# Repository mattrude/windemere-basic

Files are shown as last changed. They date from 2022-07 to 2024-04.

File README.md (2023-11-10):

# Windemere Basic 6502 Computer

This is a proof of concept project to build a 65c02 computer from scratch.

This repository is broken up into 2 main sections, [Hardware](Hardware#readme) and [Software](SourceCode#readme).

## About

                 ┌───────────────────────────┐
                 │    WD65C02 Memory Map     │
                 ├───────┬───────────────────┤
                 │ $0000 │                   │
                 │       │   Zero Page RAM   │
                 │ $00ff │                   │
                 ├───────┼───────────────────┤
                 │ $0100 │///////////////////│
                 │       │////// Stack //////│
                 │ $01ff │///////////////////│
                 ├───────┼───────────────────┤
                 │ $0200 │                   │
                 │       │        RAM        │
                 │ $5fff │                   │
                 ├───────┼───────────────────┤
                 │ $6000 │                   │
                 │       │    W65C22S VIA    │
                 │ $600f │                   │
                 ├───────┼───────────────────┤
                 │ $6010 │                   │
                 │       │    (Not Used)     │
                 │ $7fff │                   │
                 ├───────┼───────────────────┤
                 │ $8000 │                   │
                 │       │        ROM        │
                 │ $ffff │                   │
                 └───────┴───────────────────┘

     ┌────────────────────────────────────────────────────────┐
     │                 Zero Page RAM Locations                │
     ├────────────────────────────────────────────────────────┤
     │ 0000: -- -- -- -- -- -- -- --  -- -- -- -- -- -- -- -- │
     │ 0010: -- -- -- -- -- -- -- --  -- -- -- -- -- -- -- -- │
     │ 0020: -- -- -- -- -- -- -- --  -- -- -- -- -- -- -- -- │
     │ 0030: -- -- -- -- -- -- -- --  -- -- -- -- -- -- -- -- │
     │ 0040: -- -- -- -- -- -- -- --  -- -- -- -- -- -- -- -- │
     │ 0050: -- -- -- -- -- -- -- --  -- -- -- -- -- -- -- -- │
     │ 0060: -- -- -- -- -- -- -- --  -- -- -- -- -- -- -- -- │
     │ 0070: -- -- -- -- -- -- -- --  -- -- -- -- -- -- -- -- │
     │ 0080: -- -- -- -- -- -- -- --  -- -- -- -- -- -- -- -- │
     │ 0090: -- -- -- -- -- -- -- --  -- -- -- -- -- -- -- -- │
     │ 00a0: -- -- -- -- -- -- -- --  -- -- -- -- -- -- -- -- │
     │ 00b0: -- -- -- -- -- -- -- --  -- -- -- -- -- -- -- -- │
     │ 00c0: -- -- -- -- -- -- -- --  -- -- -- -- -- -- -- -- │
     │ 00d0: -- -- -- -- -- -- -- --  -- -- -- -- -- -- -- -- │
     │ 00e0: -- -- -- -- -- -- -- --  -- -- -- -- -- -- -- -- │
     │ 00f0: 00 00 00 00 00 00 00 00  -- -- -- -- -- -- -- -- │
     └────────────────────────────────────────────────────────┘

## Required Tools/Software

### Software Used

* [KiCad](https://www.kicad.org/) - To create the Schematic and PCB
* [vasm](http://sun.hasenbraten.de/vasm/) - To compile the Source Code
* [miniPro](https://gitlab.com/DavidGriffith/minipro) - To upload the compiled binary to an eeprom
* [ClickCharts](https://www.nchsoftware.com/chart/index.html) - To create flowchart's for project documentation.

### Compiling from source

This source file expects the use of the vasm compiler found at: [sun.hasenbraten.de/vasm](http://sun.hasenbraten.de/vasm/)

To compile this code, run a command similer to:

    vasm6502_oldstyle -c02 -dotdir -Fbin main.asm -o main.bin

## System Images

Schematic

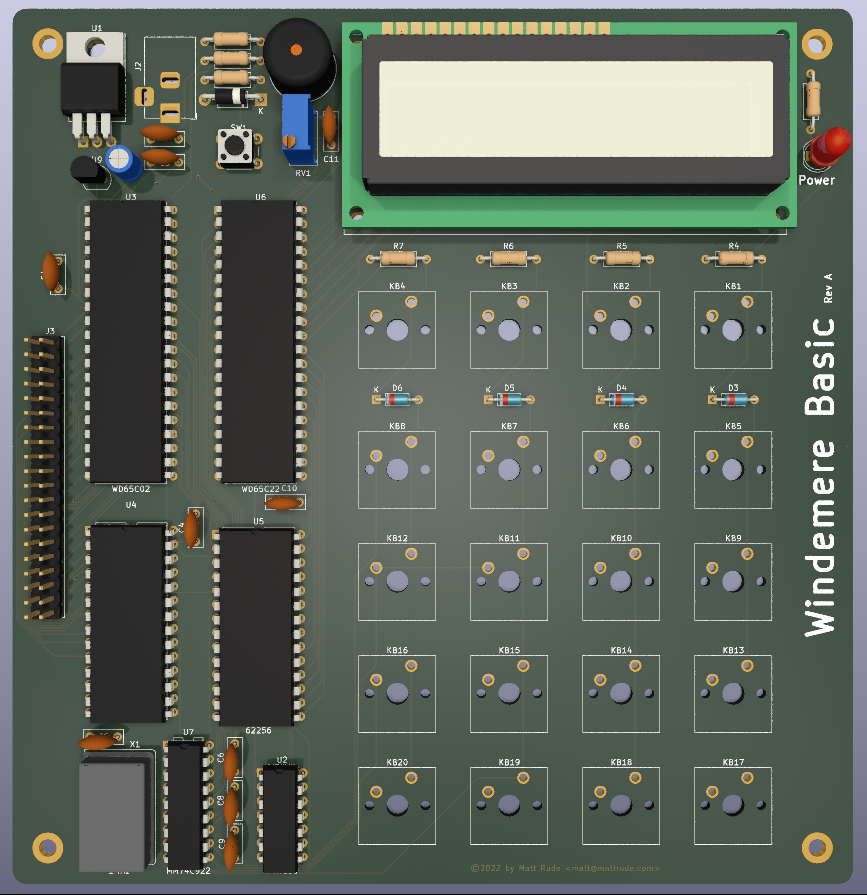
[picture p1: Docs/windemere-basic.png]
PCB


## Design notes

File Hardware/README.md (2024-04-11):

# Hardware

The file describes the layout of the board and how components are used.

## Control Logic

The control logic enables the different components connected to the registry according to the address requested by the 65C02 CPU. We accomplish this primarily by using 3 channels of a 4 channel NAND gate, the [74LS00](https://www.ti.com/lit/gpn/sn74ls00).

1. We start by flipping the bit of `A15` registry line by using two gates of a NAND gate. The inverted output is sent first to the `CS` (chip select) line of the EEPROM. This enables the ROM when the address requested on the registry bus is `$8000` or above and disables the chip when the address is below `$7FFF`.

2. The above inverted `A15` line from the NAND gate continues to one channel of a second NAND gate.  The other channel of this gate is connected to the `PHI2` clock signal, with it's output connected to the `CS` pin of the RAM chip.  The ROM chip also has it's `OE` (output enabled) pin connected to `A14`.  The `OE` pin is active low, so the RAM chip is only active between `$0000` to `$4FFF`.

3. The same inverted `A15` line from the first NAND gate is used a third time, this time in coordination with the `A14` line.  The output from this third gate connects to the `CS` pin of the WD65C22 VIA chip, enabling access in the `$6000`

## W65C22 VIA

The [W65C22](https://www.westerndesigncenter.com/wdc/documentation/w65c22.pdf) Versatile Interface Adapter (VIA) is a flexible I/O device used to connect to the [LCD Screen](#lcd-screen), [20-Button Keypad](#20-button-keypad) and used in software for it's timers.

As described in part 3 of the control logic section above, the VIA chip is accessed within the `$6000` address block.

```armasm
lda #$ff                ; Set all pins on port "B" to output
sta $6002               ; Store to port B on the W65C22
lda #$e1                ; top 3 pins/last, port "A" to output
sta $6003               ; Store to port A on the W65C22
```

## LCD Screen

The liquid crystal display (LCD) screen module is a Hitachi [HD44780](https://www.sparkfun.com/datasheets/LCD/HD44780.pdf) LCD controller is an alphanumeric dot matrix LCD controller developed by Hitachi in the 1980s. The character set of the controller includes ASCII characters, Japanese Kana characters, and some symbols in two 40 character lines.

```armasm
; To initialize the LCD screen via the W65C22

PORTB = $6000               ; W65C22 Register "B"
PORTA = $6001               ; W65C22 Register "A"
DDRB  = $6002               ; W65C22 Data Direction Register "B"
DDRA  = $6003               ; W65C22 Data Direction Register "A"
EN    = $80                 ; HD44780U LCD Starts data read/write
RW    = $40                 ; HD44780U LCD Enables Screen to read data
RS    = $20                 ; HD44780U LCD Registers Select

lcd_init:
    lda #$ff                ; Set all pins on port "B" to output
    sta DDRB
    lda #$e1                ; top 3 pins/last, port "A" to output
    sta DDRA
    lda #$38                ; 8-bit mode; 2-line display; 5x8 font
    jsr lcd_config
    lda #$c                 ; Display on; cursor on; blink off
    jsr lcd_config
    lda #$6                 ; Increment and shift cursor
    jsr lcd_config
    lda #$11                ; Clear the LCD display
    jsr lcd_config
    lda #$2                 ; Send cursor to line 1
    jsr lcd_config
loop:
    jmp loop                ; INIT is now complete

lcd_config:
    jsr lcd_wait             ; Jump to the lcd_wait subroutine
    sta PORTB
    lda #0                  ; Clear LCD RS/RW/EN bits
    sta PORTA
    lda #EN                 ; Set LCD EN (enable) bit
    sta PORTA
    lda #0                  ; Clear LCD RS/RW/EN bits
    sta PORTA
    rts                     ; Return from Subroutine

lcd_wait:
    pha                     ; Push Accumulator to Stack
    lda #%00000000          ; Set Port B as an input
    sta DDRB                ; Load the setting to Port "B"
lcd_busy:
    lda #RW                 ; Set port to Read/Write
    sta PORTA               ; Load the setting to Port "A"
    lda #(RW | EN)          ; Set port to Read/Write & Enable
    sta PORTA               ; Load the setting to Port "A"
    lda PORTB               ; Load Accumulator with Port "B"
    and #%10000000          ; Combine the above with $80
    bne lcd_busy            ; Jump back to the top of lcd_busy
    lda #RW                 ; Set port to Read/Write
    sta PORTA               ; Load the setting to Port "A"
    lda #%11111111          ; Port B is output
    sta DDRB                ; Load the setting to Port "B"
    pla                     ; Pull Accumulator from Stack
    rts                     ; Return from Subroutine
```

## 20-Button Keypad

For the 20-button keypad we use the [MM74C923](https://mm.digikey.com/Volume0/opasdata/d220001/medias/docus/1001/MM74C922,923.pdf) 20-Key Encoder connected to the above W65C22 VIA chip.

When a button is pressed, the chip will set the output as described below and set the `DA` (Data Available) pin, connected to the `CA1` pin on the W65C22, to high.

| W65C22 VIA  | MM74C923 |
| --- | --- |
| PA0 (pin 2) | A (pin 19) |
| PA1 (pin 3) | B (pin 18) |
| PA2 (pin 4) | C (pin 17) |
| PA3 (pin 5) | D (pin 16) |
| PA4 (pin 6) | E (pin 15) |

Below is a Simple key map with the left hand column showing the pin id as described above and the top row is the button id pressed.

| | 0 | 1 | 2 | 3 | 4 | 5 | 6 | 7 | 8 | 9 | 10 | 11 | 12 | 13 | 14 | 15 | 16 | 17 | 18 | 19 |
|---|---|---|---|---|---|---|---|---|---|---|----|----|----|----|----|----|----|----|----|----|
| A | - | 1 | - | 1 | - | 1 | - | 1 | - | 1 | -  | 1  | -  | 1  | -  | 1  | -  | 1  | -  | 1  |
| B | - | - | 1 | 1 | - | - | 1 | 1 | - | - | 1  | 1  | -  | -  | 1  | 1  | -  | -  | 1  | 1  |
| C | - | - | - | - | 1 | 1 | 1 | 1 | - | - | -  | -  | 1  | 1  | 1  | 1  | -  | -  | -  | -  |
| D | - | - | - | - | - | - | - | - | 1 | 1 | 1  | 1  | 1  | 1  | 1  | 1  | -  | -  | -  | -  |
| E | - | - | - | - | - | - | - | - | - | - | -  | -  | -  | -  | -  | -  | 1  | 1  | 1  | 1  |

## Reset Circuit

The reset circuit consist of a [MCP102-475](https://www.microchip.com/en-us/product/mcp102) voltage supervisor device designed to keep a processor in reset until the system voltage has reached and stabilized at the proper level 4.75 volts for 120ms.

## References & Notes

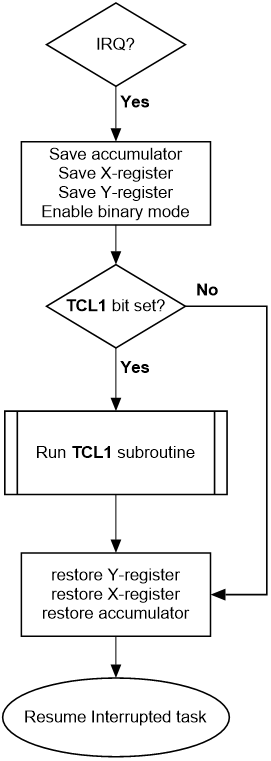
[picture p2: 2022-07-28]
Docs/IRQ-Flowchart.png

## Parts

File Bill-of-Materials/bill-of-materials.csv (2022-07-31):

Item | Qty | Reference(s) | Value | Digikey Part | Mouser Part
1 | 1 | BZ1 | Buzzer | 102-1156-ND | 490-CEM-1212S
2 | 2 | C1, C8 | 1uF | 399-13743-1-ND | 80-C322C105K5R9170-R
3 | 7 | C2, C3, C4, C5, C6, C7, C9 | 0.1uF | 399-9877-1-ND | 80-C322C104K5R-TR
4 | 1 | C10 | 1µF | 493-11321-3-ND | 80-ESC105M050AC3AA
5 | 1 | C11 | 0.1uF | 399-9877-1-ND | 80-C322C104K5R-TR
6 | 2 | D1, D2 | LED_Red | 160-1087-ND | 859-LTL-10223W
7 | 1 | D3 | 1N5819 | 1N5819GOS-ND | 863-1N5819G
8 | 4 | D4, D5, D6, D7 | 1N914 | 1N914FS-ND | 512-1N914
9 | 2 | J1, J2 | A_40-LC-TT | AE10008-ND | 517-4840-6004-CP
10 | 1 | J3 | Connector | 732-5310-ND | 855-M20-9982045
11 | 2 | J4, J5 | A_28-LC-TT | AE10004-ND | 517-4828-3004-CP
12 | 1 | J6 | Barrel_Jack | CP-018H-ND | 490-PJ-018H
13 | 20 | KB1, KB2, KB3, KB4, KB5, KB6, KB7, KB8, KB9, KB10, KB11, KB12, KB13, KB14, KB15, KB16, KB17, KB18, KB19, KB20 | Push_Button | CH162-ND | 540-MX1A-11NN
14 | 3 | R1, R2, R5 | 1K | CF14JT1K00CT-ND | 660-CFP1/4CT52R102J
15 | 2 | R3, R4 | 1K | CF14JT1K00CT-ND | 660-CFP1/4CT52R102J
16 | 4 | R6, R7, R8, R9 | 100K | CF14JT100KCT-ND | 660-CF1/2CT52R104J
17 | 1 | RV1 | 10K | 490-2875-ND | 81-PV36W103C01B00
18 | 1 | SW1 | Reset Button | 401-1978-ND | 611-D6R90LFS
19 | 1 | U1 | HD44780U | 2470-ACM1602KC-NLW-BBW-R-ND | 485-181
20 | 1 | U2 | WD65C02 |  | 955-W65C02S6TPG-14
21 | 1 | U3 | 28C256 | AT28C256-15PU-ND | 556-AT28C25615PU
22 | 1 | U4 | 62256 | 1450-1033-ND | 913-AS6C62256-55PCN
23 | 1 | U5 | WD65C22 |  | 955-W65C22S6TPG-14
24 | 1 | U6 | 74HC00 | 2156-CD74HC00E-HC-ND | 595-CD74HC00E
25 | 1 | U7 | MM74C922
26 | 1 | U8 | L7805 | 497-1443-5-ND | 511-L7805CV
27 | 1 | U9 | MCP102-475 | MCP102-475E/TO-ND | 579-MCP102-475E/TO
28 | 1 | X1 | 1MHz | X937-ND | 520-TCF100-X

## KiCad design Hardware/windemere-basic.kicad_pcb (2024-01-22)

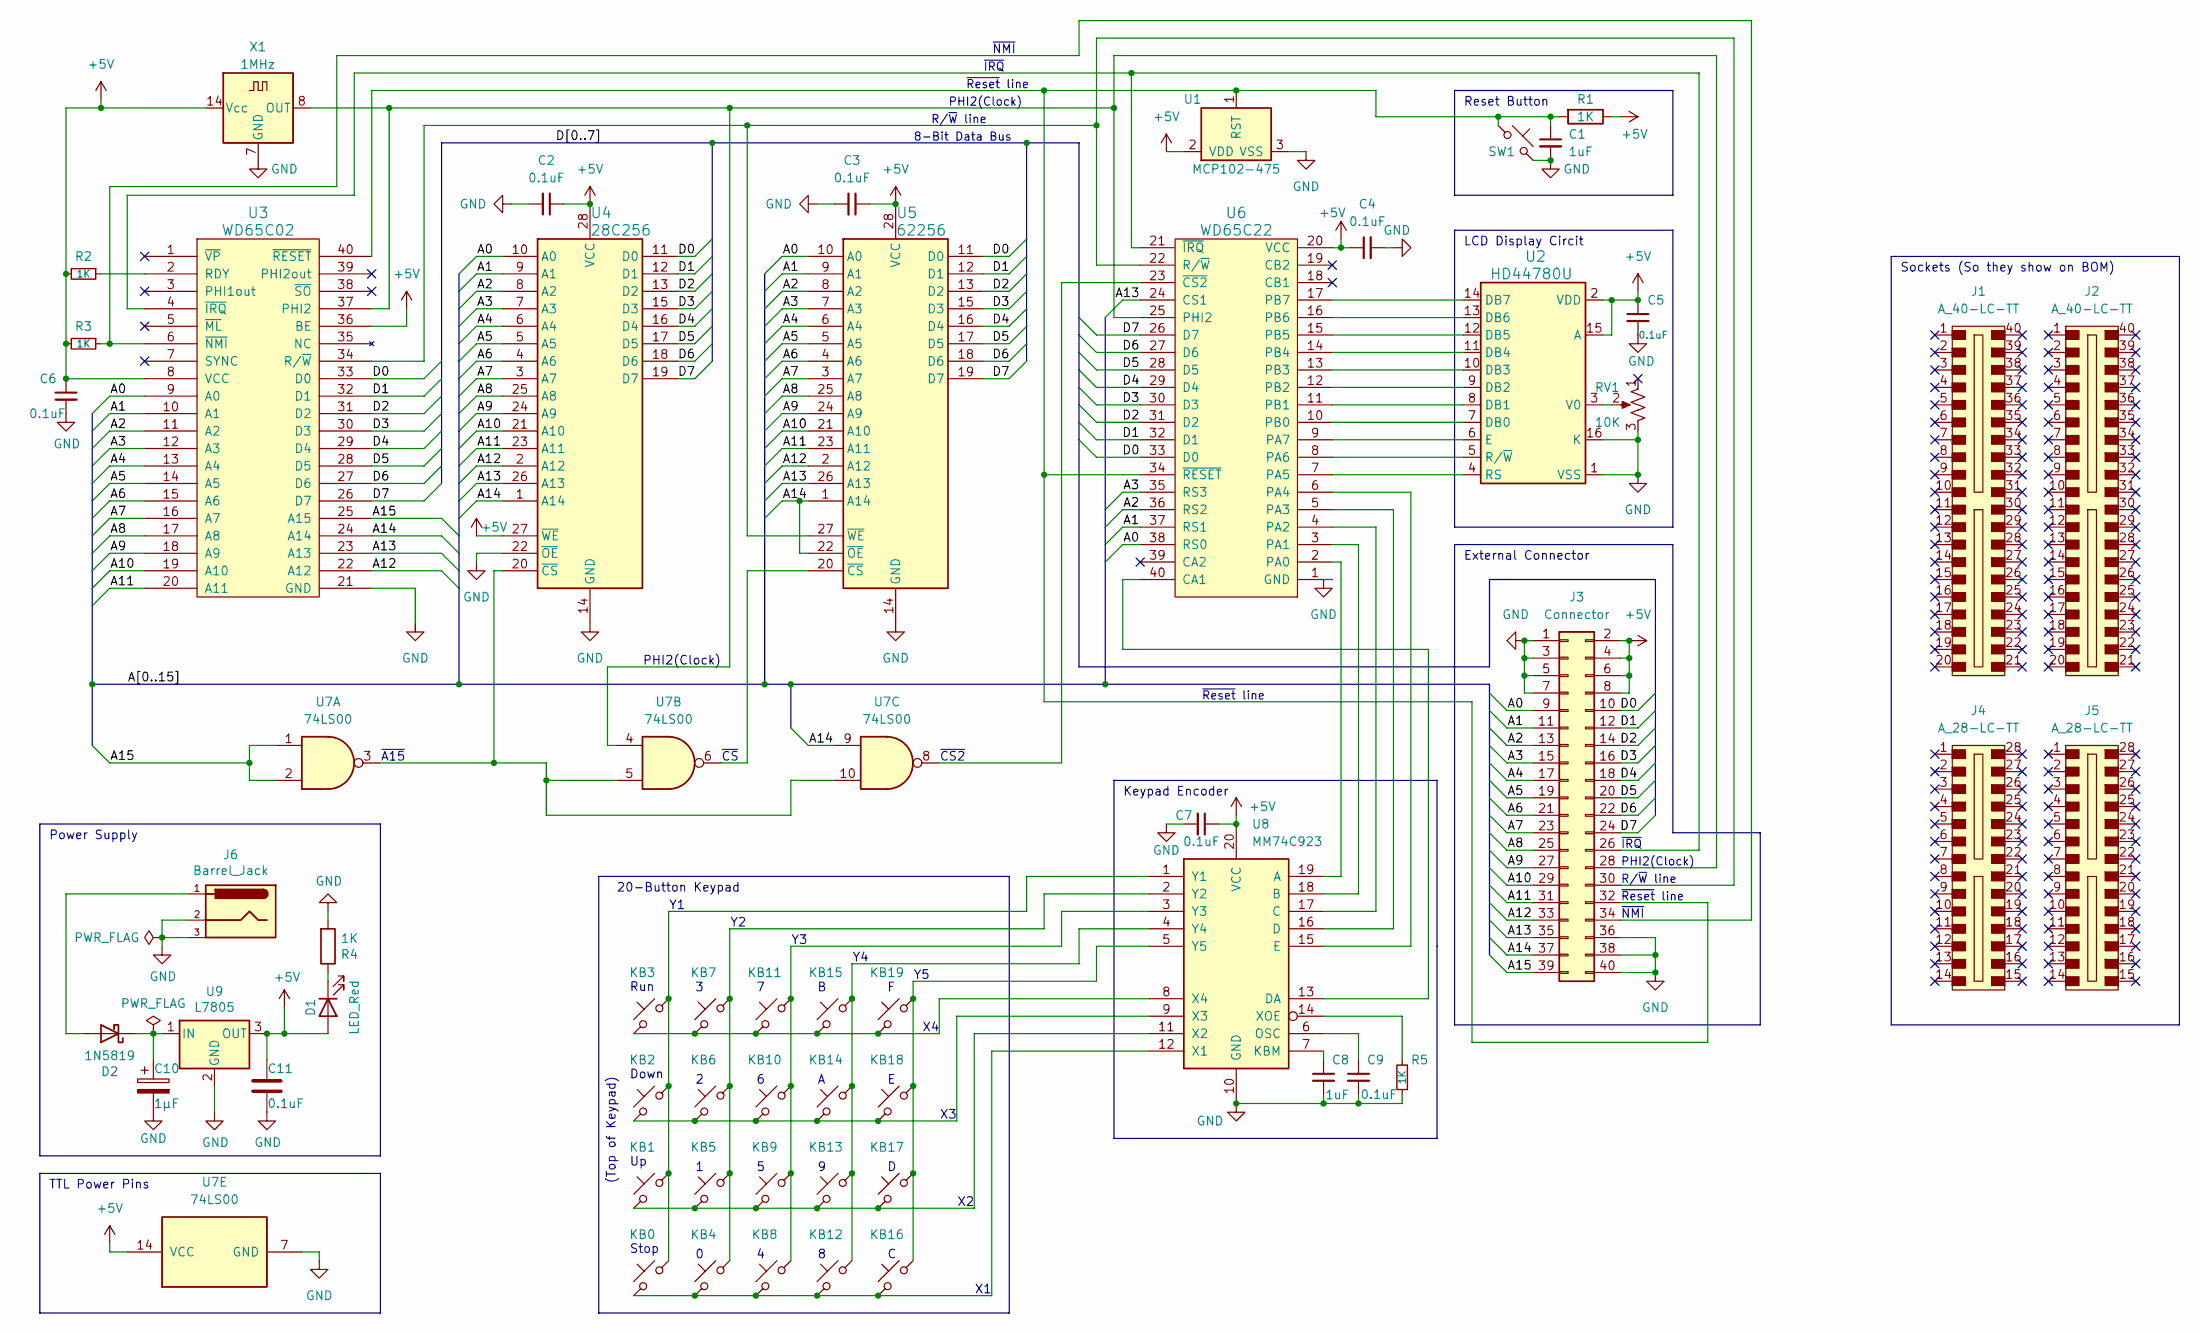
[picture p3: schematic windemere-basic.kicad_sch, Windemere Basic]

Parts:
C1, C8: 1uF; C_Disc_D7.0mm_W2.5mm_P5.00mm; Mouser Part 80-C322C105K5R9170-R; Digikey Part 399-13743-1-ND
C2, C3, C4, C5, C6, C7, C9, C11: 0.1uF; C_Disc_D7.0mm_W2.5mm_P5.00mm; Mouser Part 80-C322C104K5R-TR; Digikey Part 399-9877-1-ND
C10: 1µF; C_Radial_D4.0mm_H7.0mm_P1.50mm; Mouser Part 80-ESC105M050AC3AA; Digikey Part 493-11321-3-ND
D1: LED_Red; LED_D5.0mm; Mouser Part 859-LTL-10223W; Digikey Part 160-1087-ND
D2: 1N5819; D_DO-41_SOD81_P10.16mm_Horizontal; Mouser Part 863-1N5819G; Digikey Part 1N5819GOS-ND
J1, J2: A_40-LC-TT; Socket_DIP-40_15.24mm_Conn; Mouser Part 517-4840-6004-CP; Digikey Part ED90059-ND
J3: Connector; PinHeader_2x20_P2.54mm_Vertical; Mouser Part 855-M20-9982045; Digikey Part 732-5310-ND
J4, J5: A_28-LC-TT; Socket_DIP-28_15.24mm_Conn; Mouser Part 517-4828-3004-CP; Digikey Part ED90057-ND
J6: Barrel_Jack; BarrelJack_Horizontal; Mouser Part 490-PJ-018H; Digikey Part CP-018H-ND
KB0, KB1, KB2, KB3, KB4, KB5, KB6, KB7, KB8, KB9, KB10, KB11, KB12, KB13, KB14, KB15, KB16, KB17, KB18, KB19: Push_Button; SW_Cherry_MX_1.00u_PCB; Mouser Part 540-MX1A-11NN; Digikey Part CH162-ND
R1, R2, R3, R4, R5: 1K; R_Axial_DIN0207_L6.3mm_D2.5mm_P10.16mm_Horizontal; Mouser Part 660-CFP1/4CT52R102J; Digikey Part CF14JT1K00CT-ND
RV1: 10K; Potentiometer_Bourns_3296W_Vertical; Mouser Part 81-PV36W103C01B00; Digikey Part 490-2875-ND
SW1: Reset Button; SW_PUSH_6mm; Mouser Part 611-D6R90LFS; Digikey Part 401-1978-ND
U1: MCP102-475; TO-92; Mouser Part 579-MCP102-475E/TO; Digikey Part MCP102-475E/TO-ND
U2: HD44780U; WC1602A; Mouser Part 485-181; Digikey Part 2470-ACM1602KC-NLW-BBW-R-ND
U3: WD65C02; DIP-40_W15.24mm; Mouser Part 955-W65C02S6TPG-14
U4: 28C256; eeprom_socket; Mouser Part 556-AT28C25615PU; Digikey Part AT28C256-15PU-ND
U5: 62256; DIP-28_W15.24mm; Mouser Part 913-AS6C62256-55PCN; Digikey Part 1450-1033-ND
U6: WD65C22; DIP-40_W15.24mm; Mouser Part 955-W65C22S6TPG-14
U7: 74LS00; DIP-14_W7.62mm; Mouser Part 595-CD74HC00E; Digikey Part 2156-CD74HC00E-HC-ND
U8: MM74C923; DIP-20_W7.62mm
U9: L7805; TO-220-3_Horizontal_TabDown; Mouser Part 511-L7805CV; Digikey Part 497-1443-5-ND
X1: 1MHz; Oscillator_DIP-14; Mouser Part 520-TCF100-X; Digikey Part X937-ND

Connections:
+5V: C2.1, C3.1, C4.1, C5.1, C6.1, C7.1, C11.1, D1.2 (A), J3.2, J3.4, J3.6, J3.8, R1.1, R2.2, R3.2, U1.2 (VDD), U2.2 (VDD), U2.15 (A), U3.8 (VCC), U3.36 (BE), U4.27 (~WE), U4.28 (VCC), U5.28 (VCC), U6.20 (VCC), U7.14 (VCC), U8.20 (VCC), U9.3 (OUT), X1.14 (Vcc)
/A0: J3.9, U3.9 (A0), U4.10 (A0), U5.10 (A0), U6.38 (RS0)
/A1: J3.11, U3.10 (A1), U4.9 (A1), U5.9 (A1), U6.37 (RS1)
/A2: J3.13, U3.11 (A2), U4.8 (A2), U5.8 (A2), U6.36 (RS2)
/A3: J3.15, U3.12 (A3), U4.7 (A3), U5.7 (A3), U6.35 (RS3)
/A4: J3.17, U3.13 (A4), U4.6 (A4), U5.6 (A4)
/A5: J3.19, U3.14 (A5), U4.5 (A5), U5.5 (A5)
/A6: J3.21, U3.15 (A6), U4.4 (A6), U5.4 (A6)
/A7: J3.23, U3.16 (A7), U4.3 (A7), U5.3 (A7)
/A8: J3.25, U3.17 (A8), U4.25 (A8), U5.25 (A8)
/A9: J3.27, U3.18 (A9), U4.24 (A9), U5.24 (A9)
/A10: J3.29, U3.19 (A10), U4.21 (A10), U5.21 (A10)
/A11: J3.31, U3.20 (A11), U4.23 (A11), U5.23 (A11)
/A12: J3.33, U3.22 (A12), U4.2 (A12), U5.2 (A12)
/A13: J3.35, U3.23 (A13), U4.26 (A13), U5.26 (A13), U6.24 (CS1)
/A14: J3.37, U3.24 (A14), U4.1 (A14), U5.1 (A14), U5.22 (~OE), U7.9
/A15: J3.39, U3.25 (A15), U7.1, U7.2
/D0: J3.10, U3.33 (D0), U4.11 (D0), U5.11 (D0), U6.33 (D0)
/D1: J3.12, U3.32 (D1), U4.12 (D1), U5.12 (D1), U6.32 (D1)
/D2: J3.14, U3.31 (D2), U4.13 (D2), U5.13 (D2), U6.31 (D2)
/D3: J3.16, U3.30 (D3), U4.15 (D3), U5.15 (D3), U6.30 (D3)
/D4: J3.18, U3.29 (D4), U4.16 (D4), U5.16 (D4), U6.29 (D4)
/D5: J3.20, U3.28 (D5), U4.17 (D5), U5.17 (D5), U6.28 (D5)
/D6: J3.22, U3.27 (D6), U4.18 (D6), U5.18 (D6), U6.27 (D6)
/D7: J3.24, U3.26 (D7), U4.19 (D7), U5.19 (D7), U6.26 (D7)
GND: C1.2, C2.2, C3.2, C4.2, C5.2, C6.2, C7.2, C8.2, C9.2, C10.2, C11.2, J3.1, J3.3, J3.5, J3.7, J3.36, J3.38, J3.40, J6.2, J6.3, R4.2, R5.1, RV1.3, SW1.1, U1.3 (VSS), U2.1 (VSS), U2.16 (K), U3.21 (GND), U4.14 (GND), U4.22 (~OE), U5.14 (GND), U6.1 (GND), U7.7 (GND), U8.10 (GND), U9.2 (GND), X1.7 (GND); also elsewhere on the board
unnamed: D1.1 (K), R4.1
unnamed: D2.2 (A), J6.1
unnamed: C10.1, D2.1 (K), U9.1 (IN)
unnamed: J3.26, U3.4 (~IRQ), U6.21 (~IRQ)
unnamed: J3.28, U3.37 (PHI2), U6.25 (PHI2), U7.4, X1.8 (OUT)
unnamed: J3.30, U3.34 (R/~W), U5.27 (~WE), U6.22 (R/~W)
unnamed: C1.1, J3.32, R1.2, SW1.2, U1.1 (RST), U3.40 (~RESET), U6.34 (~RESET)
unnamed: J3.34, R3.1, U3.6 (~NMI)
unnamed: U2.7 (DB0), U6.10 (PB0)
unnamed: U2.8 (DB1), U6.11 (PB1)
unnamed: U2.9 (DB2), U6.12 (PB2)
unnamed: U2.10 (DB3), U6.13 (PB3)
unnamed: U2.11 (DB4), U6.14 (PB4)
unnamed: U2.12 (DB5), U6.15 (PB5)
unnamed: U2.13 (DB6), U6.16 (PB6)
unnamed: U2.14 (DB7), U6.17 (PB7)
unnamed: U2.6 (E), U6.9 (PA7)
unnamed: U2.4 (RS), U6.7 (PA5)
unnamed: U2.5 (R/~W), U6.8 (PA6)
unnamed: RV1.2, U2.3 (V0)
unnamed: R2.1, U3.2 (RDY)
unnamed: U4.20 (~CS), U7.3, U7.5, U7.10
unnamed: U5.20 (~CS), U7.6
unnamed: U6.40 (CA1), U8.13 (DA)
unnamed: U6.2 (PA0), U8.19 (A)
unnamed: U6.3 (PA1), U8.18 (B)
unnamed: U6.4 (PA2), U8.17 (C)
unnamed: U6.5 (PA3), U8.16 (D)
unnamed: U6.6 (PA4), U8.15 (E)
unnamed: U6.23 (~CS2), U7.8
unnamed: C8.1, U8.7 (KBM)
unnamed: C9.1, U8.6 (OSC)
unnamed: KB0.1, KB4.1, KB8.1, KB12.1, KB16.1, U8.12 (X1)
unnamed: KB1.1, KB5.1, KB9.1, KB13.1, KB17.1, U8.11 (X2)
unnamed: KB2.1, KB6.1, KB10.1, KB14.1, KB18.1, U8.9 (X3)
unnamed: KB3.1, KB7.1, KB11.1, KB15.1, KB19.1, U8.8 (X4)
unnamed: R5.2, U8.14 (XOE)
unnamed: KB0.2, KB1.2, KB2.2, KB3.2, U8.1 (Y1)
unnamed: KB4.2, KB5.2, KB6.2, KB7.2, U8.2 (Y2)
unnamed: KB8.2, KB9.2, KB10.2, KB11.2, U8.3 (Y3)
unnamed: KB12.2, KB13.2, KB14.2, KB15.2, U8.4 (Y4)
unnamed: KB16.2, KB17.2, KB18.2, KB19.2, U8.5 (Y5)

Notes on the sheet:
Sockets (So they show on BOM)
PHI2(Clock)
20-Button Keypad
(Top of Keypad)
LCD Display Circit
Keypad Encoder
~{Reset} line
Stop
8-Bit Data Bus
Run
~{CS2}
Power Supply
~{IRQ}
~{A15}
Down
Reset Button
R/~{W} line
External Connector
~{NMI}
TTL Power Pins
~{CS}

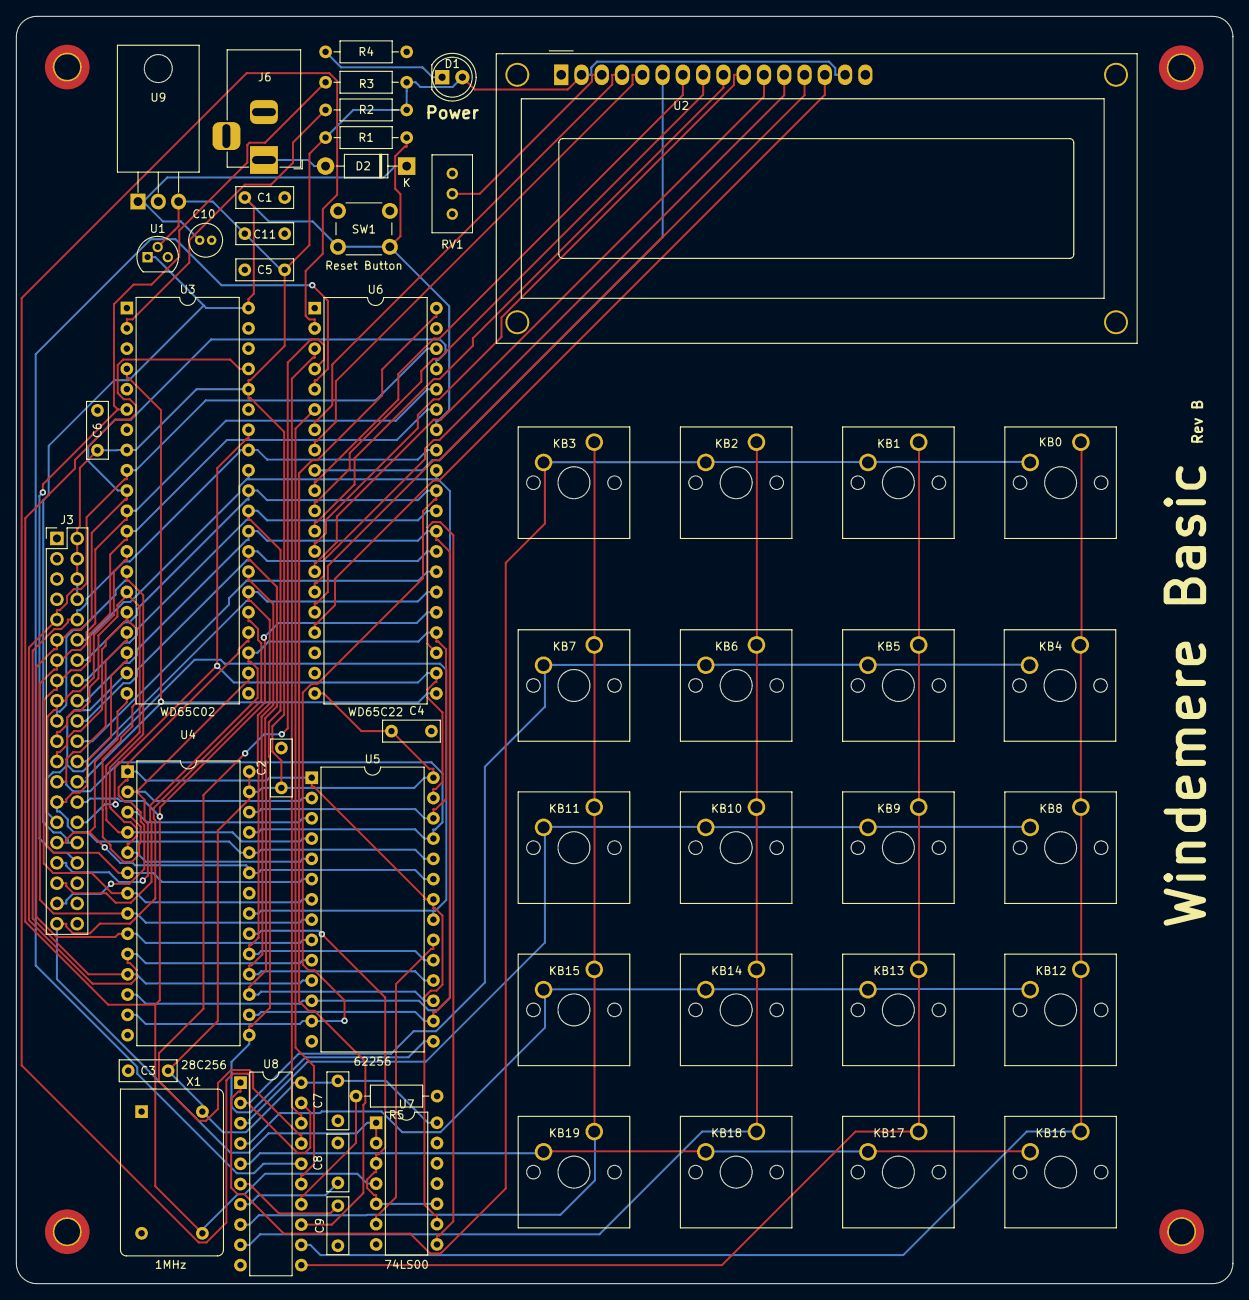
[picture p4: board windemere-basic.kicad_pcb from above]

Board: 2 copper layers, 152.4 x 158.8 mm, 57 parts (0 on the bottom side), 68 nets.

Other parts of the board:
REF1, REF2, REF3, REF4: MountingHole_3.2mm_M3_DIN965_Pad_TopBottom
memory_map: 6502-Memory_Map

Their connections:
GND: REF1.1, REF2.1, REF3.1, REF4.1; also elsewhere on the board

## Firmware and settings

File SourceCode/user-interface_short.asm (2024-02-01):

;   Name: User Interface - Short
;   File: user-interface_short.asm
;   Author: Matt Rude <matt@mattrude.com>
;   URL: https://github.com/mattrude/windemere-basic
;   Date: 2022-01-22
;   Version: 0.1.0-Alpha
;
; -----------------------------------------------------------------------------
;   Program Summary
;
;
;   The below code is written for a W65C02 connected to a W65C22 (VIA)
;
; -----------------------------------------------------------------------------
;   Compiling from source
;
;
;   This source file expects the use of the vasm compiler found at:
;       http://sun.hasenbraten.de/vasm/
;
;   To compile this code, run a command similer to:
;       vasm6502_oldstyle -c02 -dotdir -Fbin main.asm -o main.bin
;
;       ..\..\..\Tools\vasm6502\vasm6502_oldstyle.exe -c02 -dotdir
;       -L user-interface_short.lst -Lall -Fbin user-interface_short.asm
;       -o user-interface_short.bin
;
; -----------------------------------------------------------------------------
;   Memory
;
;                 ┌───────────────────────────┐
;                 │    WD65C02 Memory Map     │
;                 ├───────┬───────────────────┤
;                 │ $0000 │                   │
;                 │       │  Zero Page (RAM)  │
;                 │ $00ff │                   │
;                 ├───────┼───────────────────┤
;                 │ $0100 │///////////////////│
;                 │       │////// Stack //////│
;                 │ $01ff │///////////////////│
;                 ├───────┼───────────────────┤
;                 │ $0200 │                   │
;                 │       │        RAM        │
;                 │ $5fff │                   │
;                 ├───────┼───────────────────┤
;                 │ $6000 │                   │
;                 │       │    W65C22S VIA    │
;                 │ $600f │                   │
;                 ├───────┼───────────────────┤
;                 │ $6010 │                   │
;                 │       │    (Not Used)     │
;                 │ $7fff │                   │
;                 ├───────┼───────────────────┤
;                 │ $8000 │                   │
;                 │       │        ROM        │
;                 │ $ffff │                   │
;                 └───────┴───────────────────┘
;
;
;
;     ┌────────────────────────────────────────────────────────┐
;     │                 Zero Page RAM Locations                │
;     ├────────────────────────────────────────────────────────┤
;     │ 0000: -- -- -- -- -- -- -- --  -- -- -- -- -- -- -- -- │
;     │ 0010: -- -- -- -- -- -- -- --  -- -- -- -- -- -- -- -- │
;     │ 0020: -- -- -- -- -- -- -- --  -- -- -- -- -- -- -- -- │
;     │ 0030: -- -- -- -- -- -- -- --  -- -- -- -- -- -- -- -- │
;     │ 0040: -- -- -- -- -- -- -- --  -- -- -- -- -- -- -- -- │
;     │ 0050: -- -- -- -- -- -- -- --  -- -- -- -- -- -- -- -- │
;     │ 0060: -- -- -- -- -- -- -- --  -- -- -- -- -- -- -- -- │
;     │ 0070: -- -- -- -- -- -- -- --  -- -- -- -- -- -- -- -- │
;     │ 0080: -- -- -- -- -- -- -- --  -- -- -- -- -- -- -- -- │
;     │ 0090: -- -- -- -- -- -- -- --  -- -- -- -- -- -- -- -- │
;     │ 00a0: -- -- -- -- -- -- -- --  -- -- -- -- -- -- -- -- │
;     │ 00b0: -- -- -- -- -- -- -- --  -- -- -- -- -- -- -- -- │
;     │ 00c0: -- -- -- -- -- -- -- --  -- -- -- -- -- -- -- -- │
;     │ 00d0: -- -- -- -- -- -- -- --  -- -- -- -- -- -- -- -- │
;     │ 00e0: -- -- -- -- -- -- -- --  -- -- -- -- -- -- -- -- │
;     │ 00f0: 00 00 00 00 00 00 00 00  -- -- -- -- -- -- -- -- │
;     └────────────────────────────────────────────────────────┘
;
; -----------------------------------------------------------------------------
;   License
;
; MIT No Attribution License
;
; Copyright (c) 2022 Matt Rude
; 
; Permission is hereby granted, free of charge, to any person obtaining
; a copy of this software and associated documentation files
; (the "Software"), to deal in the Software without restriction, including
; without limitation the rights to use, copy, modify, merge, publish,
; distribute, sublicense, and/or sell copies of the Software, and to
; permit persons to whom the Software is furnished to do so.
;
; THE SOFTWARE IS PROVIDED "AS IS", WITHOUT WARRANTY OF ANY KIND, EXPRESS OR
; IMPLIED, INCLUDING BUT NOT LIMITED TO THE WARRANTIES OF MERCHANTABILITY,
; FITNESS FOR A PARTICULAR PURPOSE AND NONINFRINGEMENT. IN NO EVENT SHALL THE
; AUTHORS OR COPYRIGHT HOLDERS BE LIABLE FOR ANY CLAIM, DAMAGES OR OTHER
; LIABILITY, WHETHER IN AN ACTION OF CONTRACT, TORT OR OTHERWISE, ARISING
; FROM, OUT OF OR IN CONNECTION WITH THE SOFTWARE OR THE USE OR OTHER
; DEALINGS IN THE SOFTWARE.
;
; -----------------------------------------------------------------------------

   ;.setcpu "65C02"             ; Declare the CPU type
    .org $FE00                  ; Start at memory location 8000 hex

;;;;;;;;;;;;;;;;;;;;;;;;;;;;;;;;;;;;;;;;;;;;;;;;;;;;;;;;;;;;;;;;;;;;;;;;;;;;;;;
;           Staic RAM Locations                                               ;
;;;;;;;;;;;;;;;;;;;;;;;;;;;;;;;;;;;;;;;;;;;;;;;;;;;;;;;;;;;;;;;;;;;;;;;;;;;;;;;
ticks    = $f0              ; 6-bytes
tocks    = $f6              ; 1-byte
cpu_type = $f7              ; 1-byte

;;;;;;;;;;;;;;;;;;;;;;;;;;;;;;;;;;;;;;;;;;;;;;;;;;;;;;;;;;;;;;;;;;;;;;;;;;;;;;;
;           W65C22 Versatile Interface Adapter (VIA)                          ;
;;;;;;;;;;;;;;;;;;;;;;;;;;;;;;;;;;;;;;;;;;;;;;;;;;;;;;;;;;;;;;;;;;;;;;;;;;;;;;;
PORTB = $6000               ; W65C22 Register "B"
PORTA = $6001               ; W65C22 Register "A"
DDRB  = $6002               ; W65C22 Data Direction Register "B"
DDRA  = $6003               ; W65C22 Data Direction Register "A"
TCL1  = $6004               ; W65C22 T1 Low-Order Counter
TCH1  = $6005               ; W65C22 T1 High-Order Counter
TLL1  = $6006               ; W65C22 T1 Low-Order Latches
TLH1  = $6007               ; W65C22 T1 High-Order Latches
TCL2  = $6008               ; W65C22 T2 Low-Order Counter
TCH2  = $6009               ; W65C22 T2 High-Order Counter
SR    = $600a               ; W65C22 Shift Register
ACR   = $600b               ; W65C22 Auxiliary Control Register
PCR   = $600c               ; W65C22 Peripheral Control Register
IFR   = $600d               ; W65C22 Interrupt Flag Register
IER   = $600e               ; W65C22 Interrupt Enable Register

;;;;;;;;;;;;;;;;;;;;;;;;;;;;;;;;;;;;;;;;;;;;;;;;;;;;;;;;;;;;;;;;;;;;;;;;;;;;;;;
;           HD44780U LCD Display Controller                                   ;
;;;;;;;;;;;;;;;;;;;;;;;;;;;;;;;;;;;;;;;;;;;;;;;;;;;;;;;;;;;;;;;;;;;;;;;;;;;;;;;
EN = $80                    ; HD44780U LCD Starts data read/write
RW = $40                    ; HD44780U LCD Enables Screen to read data
RS = $20                    ; HD44780U LCD Registers Select
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

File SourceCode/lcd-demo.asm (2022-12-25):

; 65c02 LCD 4-bit Demo code
;
; https://sigmaserv.fr/6502/lcd_2.s

PORTB = $6000
PORTA = $6001
DDRB = $6002
DDRA = $6003

E  = %00100000
RS = %00010000

    .org $8000

reset:
	lda #%01111111          ; Set pins on VIA port B to output
	sta DDRB
	
	lda #%00000010          ; Set LCD to 4-pins mode
	jsr lcd_instruction
	lda #%00000010
	jsr lcd_instruction
	lda #%00000000
	jsr lcd_instruction
	lda #%00000000
	jsr lcd_instruction
	lda #%00001110
	jsr lcd_instruction
	
	lda #%00010100
	jsr print_char
	lda #%00011000
	jsr print_char

loop:
    jmp loop
	
lcd_instruction:
	sta PORTB
	lda #0
	sta PORTB
	lda #E
	sta PORTB
	lda #0
	sta PORTB
	jsr delay
	rts
	
print_char: 
	sta PORTB
	lda #E
	sta PORTB
	lda #RS
	sta PORTB
	jsr delay
	rts

delay:
	ldx #200
delay2:
    ldy #0
delay1:
    dey
	bne delay1
	dex
	bne delay2
	rts
  
	.org $fffc
	.word reset
	.word $0000

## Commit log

2022-02-08 Starting Out
    [windemere-basic.kicad_pcb, windemere-basic.kicad_sch]
2022-02-08 Correct Site URL
    [windemere-basic.kicad_sch]
2022-02-16 footprint updates
    [windemere-basic.kicad_pcb, windemere-basic.kicad_sch]
2022-03-13 correct issues
    [windemere-basic.kicad_pcb, windemere-basic.kicad_sch]
2022-03-13 Delete 65xx-mdr2.kicad_sym
    Duplicate
2022-03-15 Add J1
    [windemere-basic.kicad_pcb, windemere-basic.kicad_sch]
2022-03-15 Added MCP102-475 to reset line
    [windemere-basic.kicad_pcb, windemere-basic.kicad_sch]
2022-03-15 added pcb image
2022-03-16 Add Digikey Part Numbers
    [windemere-basic.kicad_pcb, windemere-basic.kicad_sch]
2022-03-16 Add Zif socket to eprom
    [windemere-basic.kicad_pcb, windemere-basic.kicad_sch]
2022-03-16 update socket
    [windemere-basic.kicad_pcb, windemere-basic.kicad_sch]
2022-03-16 more socket updates
    [windemere-basic.kicad_pcb]
2022-03-18 Set Grid origin in KiCad
    [windemere-basic.kicad_pcb]
2022-03-20 update to current
    [windemere-basic.kicad_pcb, windemere-basic.kicad_sch]
2022-03-20 Update ID's
    [windemere-basic.kicad_pcb, windemere-basic.kicad_sch]
2022-03-24 Add Bypass caps
    [windemere-basic.dsn, windemere-basic.kicad_pcb, windemere-basic.kicad_sch]
2022-03-24 remove unused files
    [windemere-basic.dsn]
2022-07-25 minor footprint changes.
    [windemere-basic.kicad_pcb]
2022-07-26 update symbols
    [windemere-basic.kicad_pcb, windemere-basic.kicad_sch]
2022-07-28 Cleanup the Schematic
    [windemere-basic.kicad_pcb, windemere-basic.kicad_sch]
2022-07-30 Move to Rev B
    [windemere-basic.kicad_pcb, windemere-basic.kicad_sch]
2022-07-30 Correct buzzer
    [windemere-basic.kicad_pcb, windemere-basic.kicad_sch]
2022-07-31 correct traces
    [windemere-basic.kicad_pcb, windemere-basic.kicad_sch]
2022-07-31 update bom & gerber files
    [bill-of-materials.csv, windemere-basic.kicad_pcb]
2022-08-03 Update comments
    [windemere-basic.kicad_pcb, windemere-basic.kicad_sch]
2022-08-24 Add Description
    [windemere-basic.kicad_pcb, windemere-basic.kicad_sch]
2022-09-01 Correct side of keyboard connector
    [windemere-basic.kicad_pcb]
2022-09-21 Getting ready for release
    [windemere-basic.kicad_pcb]
2022-09-28 Change 28C256 label from fab to silk
    [windemere-basic.kicad_pcb]
2022-09-28 Correct minor spacing
    [windemere-basic.kicad_pcb]
2022-09-28 Minor part number updates
    [windemere-basic.kicad_sch]
2022-09-29 Update windemere-basic.kicad_pcb
    Minor track updates
    [windemere-basic.kicad_pcb]
2022-09-29 Remove unused text from front
    [windemere-basic.kicad_pcb]
2022-10-03 correct bin & lst files
    [user-interface.asm]
2022-11-08 Move footprint files
    Move footprint files to their own folder for easier monitoring.
2023-06-01 Moving to KiCad 7.0.5
    [windemere-basic.kicad_pcb]
2023-10-22 Migrate to KiCad 7.0.8
    [windemere-basic.kicad_sch]
2023-10-25 Correct verbiage in comment of sheet
    [windemere-basic.kicad_sch]
2023-11-08 Move KiCad to Hardware
    [windemere-basic.kicad_pcb, windemere-basic.kicad_sch]
2023-11-08 Hardware: Change from 74HC00 to 74LS00
    [windemere-basic.kicad_pcb, windemere-basic.kicad_sch]
2023-11-20 Change to MM74LS923
    [windemere-basic.kicad_pcb, windemere-basic.kicad_sch]
2023-11-21 Correct MCP102-475 Datasheet
    [windemere-basic.kicad_sch]
2023-11-24 Correct MM74C923
    [windemere-basic.kicad_pcb, windemere-basic.kicad_sch]
2023-11-24 correct direction of mm74c923
    [windemere-basic.kicad_pcb, windemere-basic.kicad_sch]
2023-12-13 Add Bypass to 74LS923
    [windemere-basic.kicad_pcb, windemere-basic.kicad_sch]
2024-01-22 Move to KiCad 8.0
    [windemere-basic.kicad_pcb, windemere-basic.kicad_sch]
2024-01-27 Update windemere-basic.kicad_sch
    correct voltage regulator
    [windemere-basic.kicad_sch]
2024-02-01 Correct top header spacing
    [user-interface_short.asm]

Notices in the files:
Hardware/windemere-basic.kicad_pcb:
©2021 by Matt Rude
